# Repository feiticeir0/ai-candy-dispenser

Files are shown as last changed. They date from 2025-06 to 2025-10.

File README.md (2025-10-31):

# Candy Machine with Voice Recognition
<div style="text-align: center;">
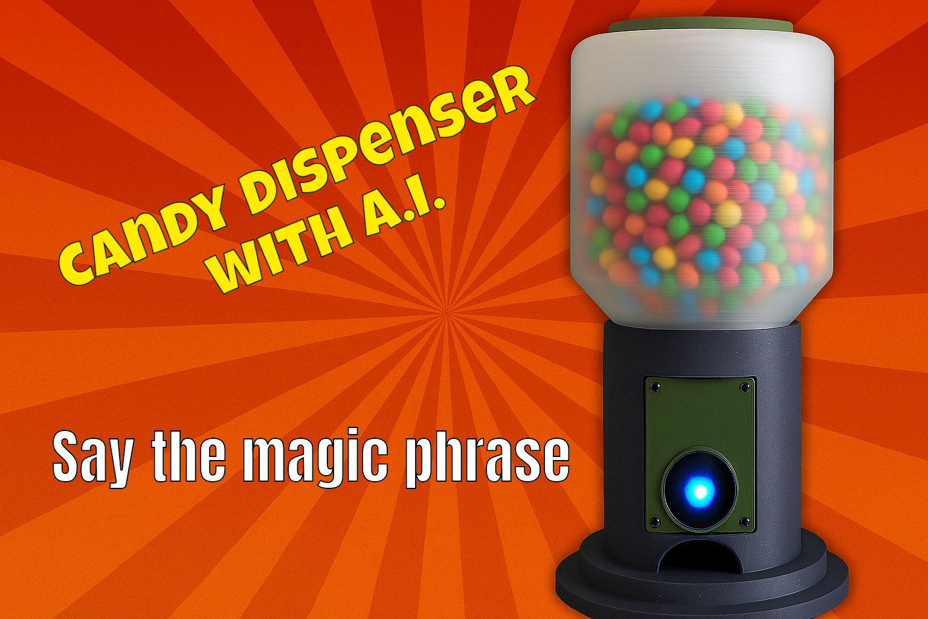
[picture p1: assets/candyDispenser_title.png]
    
</div>

This project is a tiny, AI-powered candy dispenser built with the Seeed Studio ESP32S3 Sense and the Xiao Round Display for XIAO.

Say the right magic words, and you’ll be rewarded with a cookie. 😄
If not, the screen politely tells you to try again.

---

## 📷 How It Works
1. When starting, the standy screen is shown

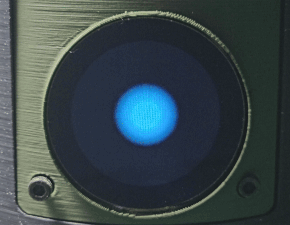
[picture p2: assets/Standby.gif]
Standby


2. The user presses the display.
3. The Xiao starts recording a phrase for **5 seconds**.

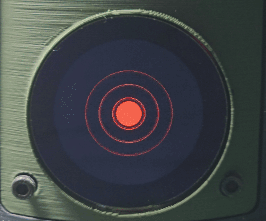
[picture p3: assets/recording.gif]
Recording


4. The phrase is sent to a **remote server**:
   - Automatically transcribes the audio using **Whisper** (OpenAI)
   - Classifies the phrase as **positive** or **negative** about chocolate or candy

5. While waitinng for a response from the server

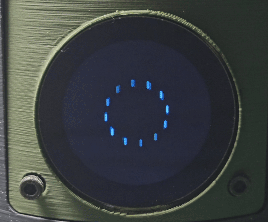
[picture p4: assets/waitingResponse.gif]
Waiting response


4. If the phrase is **positive**:

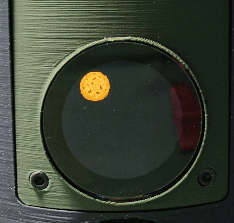
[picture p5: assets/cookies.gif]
Cookies

   - A candy is automatically **dispensed**

5. Otherwise, a image is shown asking the user to try again.

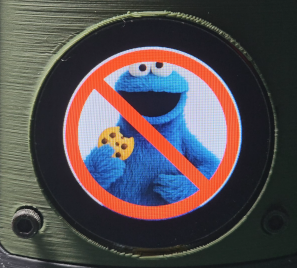
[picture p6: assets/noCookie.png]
No cookie for you


---

Project Structure

```
.
├── 3D/                       # Directory for the 3D models
├── Arduino/                  # Directory for the Arduino code
├── Jetson/                   # Directory for Jetson specific instructions
├── raspberry-pi-llm/         # Directory for running the server using a Raspberry PI
├── main.py                   # API code
├── Dockerfile                # Dockerfile for CPU
├── Dockerfile.gpu            # Dockerfile with CUDA support (GPU)
├── docker-compose.cpu.yml    # Compose file for CPU use
├── docker-compose.gpu.yml    # Compose file for GPU (NVIDIA)
```

---

## 📷 How to Use
## Server
### Deployment with Docker Compose
### ⚙️ Requirements

- Docker 20.10+
- `docker compose` (modern CLI)
- For GPU use:
  - NVIDIA drivers installed
  - `nvidia-container-toolkit`: [official guide](https://docs.nvidia.com/datacenter/cloud-native/container-toolkit/install-guide.html)

---

### 🖥️ Using with GPU (CUDA), building the image

Uses GPU to accelerate transcription and classification.

#### ✅ Requirements:

- NVIDIA GPU compatible with CUDA 11.8+
- Drivers installed (`nvidia-smi` should work)
- Docker with NVIDIA runtime
- Install the toolkit:
```bash
sudo apt-get install -y nvidia-container-toolkit
sudo systemctl restart docker
```

#### ▶️ Command:

```bash
docker compose -f docker-compose.gpu.yml up --build
```
After the command, it should start buiding the machine. 
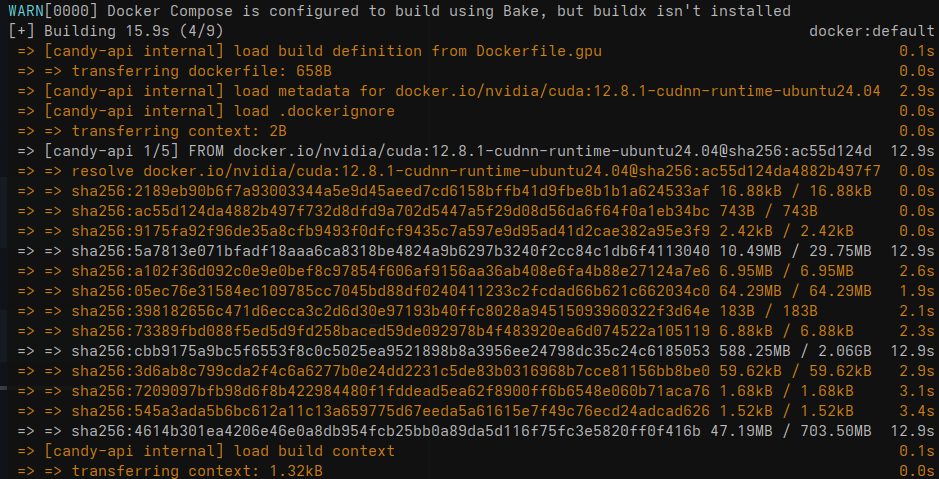
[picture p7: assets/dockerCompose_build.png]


---

### 🖥️ Using with CPU only, building the image

Simpler and portable; good for testing and light deployments.

#### ▶️ Command:

```bash
docker compose -f docker-compose.cpu.yml up --build
```

---

## ⚙️ Testing GPU (CUDA) Support

### ✅ 1. Check NVIDIA drivers
```bash
nvidia-smi
```

### ✅ 2. Install `nvidia-container-toolkit` (apt package)
```bash
sudo apt install nvidia-container-toolkit
sudo systemctl restart docker
```

### ✅ 3. Verify GPU access via Docker
```bash
docker run --rm --gpus all nvidia/cuda:11.8.0-base nvidia-smi
```

### ▶️ 4. Start with GPU (after building the image, above instructions)
```bash
docker compose -f docker-compose.gpu.yml up
```
After a bit, the container is ready and listening. 
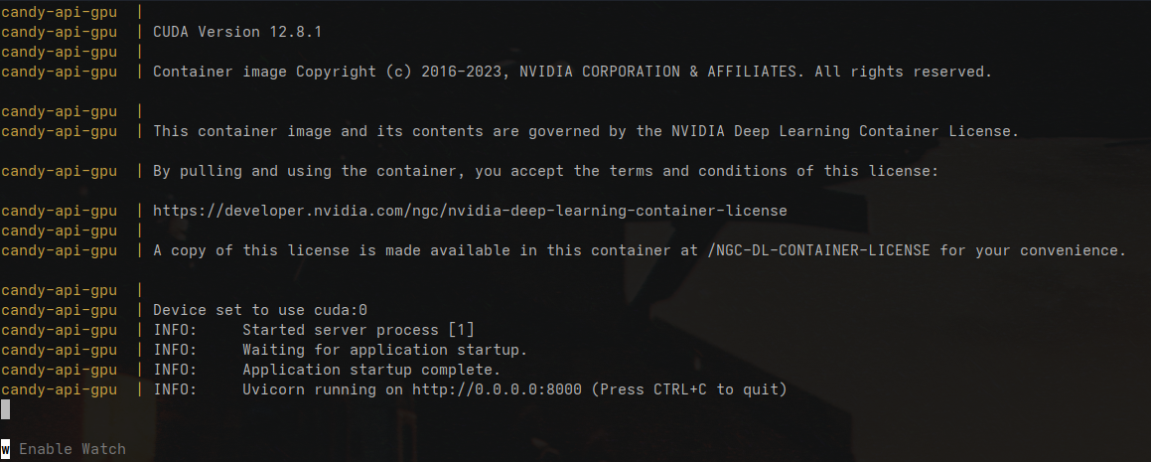
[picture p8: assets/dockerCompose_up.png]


### 5. Check if PyTorch uses CUDA
```bash
docker exec -it candy-api-gpu python3 -c "import torch; print(torch.cuda.is_available())"
```
---

## 🍬 Deployment with Jetson

If you're going to use a Nvidia Jetson (tested with Seeedstudio reComputer J4012 - Jetson Orin NX 16GB), go to [Jetson](./Jetson/README.md) folder for more information

---

## 📦 Models Used
These are the models used. You can change them in `main.py`.

- [`openai/whisper-small`](https://github.com/openai/whisper): for audio transcription
- [`facebook/bart-large-mnli`](https://huggingface.co/facebook/bart-large-mnli): for zero-shot classification

---

## Customization

- You can change the classification **labels** (`positive`, `negative`) in `main.py`
- You can switch Whisper models to `tiny`, `base`, or `large` depending on your hardware
- You can switch the language used by model for the transcription (`pt`, `en`, `es`, etc.)

### Everything is customizable

Instead of something about candy, it can be about anything. The Xiao records a 5 seconds phrase (customizable, but be aware of memory limitations - it's recorded on memory) and sends it to the server for transcription by whisper. There, you can **change** the classification labels and make it about anything. 

## 🔧 Auto-start on Boot (systemd)
For the docker image to start at boot, we need to create a Systemd file. 
Let's create the file
```bash
sudo vi /etc/systemd/system/candy-machine.service
```
Inside, place the following lines. **Here I'm using the docker compose GPU file**.

Don't forget to replace the location for your working directory, where the docker compose files are located. 

```
[Unit]
Description=Candy Machine API (Docker Compose)
Requires=docker.service
After=docker.service

[Service]
Type=oneshot
RemainAfterExit=yes
WorkingDirectory=/path/for/the/project
ExecStart=/usr/bin/docker compose -f docker-compose.cpu.yml up -d
ExecStop=/usr/bin/docker compose -f docker-compose.cpu.yml down
TimeoutStartSec=0

[Install]
WantedBy=multi-user.target
```
Reload Systemd and enable the new service.

```bash
sudo systemctl daemon-reexec
sudo systemctl daemon-reload
sudo systemctl enable candy-machine.service
```

Start it manually the first time.
```bash
sudo systemctl start candy-machine.service
```
Now, the Candy Machine will start automatically when the system starts. 

## ⚙️ Technical Notes & Troubleshooting
### 🧩 Display not showing graphics (white or black screen)

If the round display remains white or black while touch and Wi-Fi work, make sure you’re using the SeeedStudio TFT_eSPI library (not the official Bodmer version).

You can install it directly from Seeed’s GitHub:

https://github.com/Seeed-Studio/Seeed_Arduino_TFT_eSPI

### TFT_eSPI

Also verify that you’ve removed any conflicting versions of TFT_eSPI from your Arduino libraries folder before compiling.

#### ✅ Tested combination:
* Seeed_Arduino_TFT_eSPI (latest)
* PNGdec version 1.0.2 (older, keeps void callback compatibility)

### 🎧 Whisper and ffmpeg error on Jetson devices
When running the FastAPI server with systemd and a Python virtual environment, Whisper may fail with:
```bash
FileNotFoundError: [Errno 2] No such file or directory: 'ffmpeg'
```

This happens because systemd launches services with a minimal PATH that doesn’t include /usr/bin.
To fix this, the following lines are at the very beginning of main.py:
```python
# Whisper & ffmpeg fix for Jetson + systemd
import os
os.environ["PATH"] += os.pathsep + "/usr/bin:/usr/local/bin"
```
This ensures ffmpeg is always found, even when the server is started automatically at boot.
- Tested on Jetson Orin NX (JetPack 6.0)
- Environment: Python 3.10 virtualenv + systemd service

## Client (the candy dispenser)
### 3D Files
Go to the [3D](./3D/readme.md) folder for more information.

### Schematics
Go to the [Schematics](./Schematics/readme.md) folder for more information on how to wire the project. 

### Arduino Code
Go to the [Arduino](./Arduino/readme.md) folder for more information.

## 🔧 TODO
- [ ] :bulb: Add a sensor to detect motor rotation (make sure a candy exits)
- [ ] :bulb: Migrate the FastAPI server to work with a Raspbery PI AI Hat+ 
- [ ] :bulb: Check for network connection in the Xiao

# Result
Here's a video of the project running (https://www.youtube.com/watch?v=d_zhMSL0ufM)

## License
This project is free software: you can redistribute it and/or modify  
it under the terms of the [GNU General Public License](https://www.gnu.org/licenses/gpl-3.0.en.html)  
as published by the Free Software Foundation, either version 3 of the License,  
or (at your option) any later version.

This project is distributed in the hope that it will be useful,  
but WITHOUT ANY WARRANTY; without even the implied warranty of  
MERCHANTABILITY or FITNESS FOR A PARTICULAR PURPOSE. See the GNU General Public License for more details.

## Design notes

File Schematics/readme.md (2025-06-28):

## Schematics for the Candy Machine

Here are the schematics for the Candy Machine electronics component. 

You'll need:
- Seeedstudio ESP32S3 Sense (you must remove the camera)

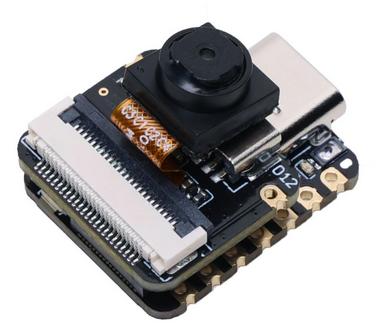
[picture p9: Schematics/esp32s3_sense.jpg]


- Seeedstudio Round display for Xiao

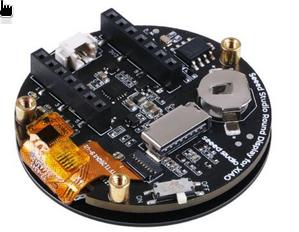
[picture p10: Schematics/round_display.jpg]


- MX1508 motor shied

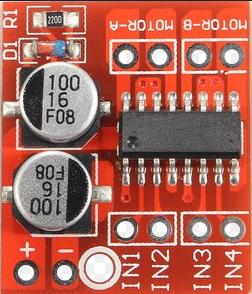
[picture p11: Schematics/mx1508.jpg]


- DC 6V Mini Gear Motor right angle

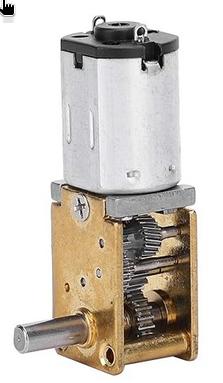
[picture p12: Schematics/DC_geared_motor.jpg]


## Schematics
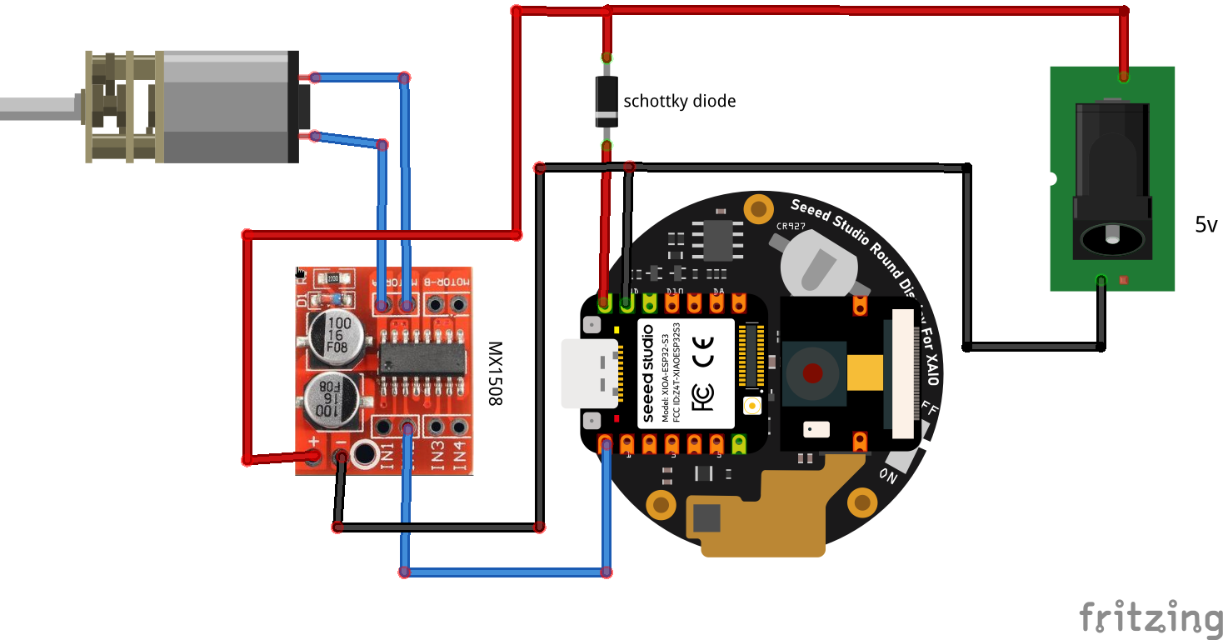
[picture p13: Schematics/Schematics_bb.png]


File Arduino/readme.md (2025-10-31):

## :electric_plug: Multitasking with FreeRTOS on the Xiao ESP323 Sense

We use the power of the ESP32-S3's dual-core architecture and the built-in FreeRTOS real-time operating system to run multiple tasks simultaneously.

We use parallel tasks (xTaskCreatePinnedToCore) to separate the application's logic into well-defined states.

### :dart: Main tasks:
```
    standbyTask: breathing animation while waiting for touch interaction.
    gravacaoTask: audio recording using the PDM microphone.
    sendTask: HTTP POST to the API and spinning loader animation.
    recordingVisualTask: animated ripple effect during recording.
    cookieTask: cookie animation + motor control to dispense the treat.
    noCookieTask: visual feedback when no cookie is dispensed.
```

### 🧩 Task coordination:
```
    Clear application states are defined to represent each phase of operation.
    A binary semaphore (semState) is used to signal and switch between tasks safely.
    Some tasks use flags (e.g., recordingVisualShouldStop) to exit gracefully and keep transitions visually coherent.
```

### ⚙️ Performance on XIAO ESP32S3 Sense

Despite its tiny form factor, the XIAO ESP32S3 Sense handles everything — from Wi-Fi connectivity and I2S audio capture to real-time sprite rendering on Round display for Xiao — all thanks to the multitasking provided by FreeRTOS.

### Uploading Code to the Seeed Studio Xiao ESP32S3 Sense

To run the Candy Machine on the Xiao ESP32S3 Sense, with microphone and the LCD (Xiao round display for XIAO), we need to configure the Arduino IDE development environment properly.

### ✅ Requirements

- Arduino IDE installed
- ESP32-S3 board added via **Boards Manager** (Espressif)
- Official `ESP32` library (v2.0.7 or higher recommended)

### Libraries
- `TFT_eSPI` - It must be from SeeedStudio - https://github.com/Seeed-Projects/SeeedStudio_TFT_eSPI
- `ArduinoJSON`
- `PNGdec` (version 1.0.2 or lower)
- `Wire`

#### Custom libraries (included in the repository)
- `CHSC6X_Touch.h` **( Xiao Round Display Touch screen)**
- `cookie.h`       **(cookie image)**
- `no_cookies.h`   **(no cookie image)**
---

Under  [files](./files) directory you'll find all the needed files for the client. 

### ⚙️ Required Settings in Arduino IDE

Set these under **Tools**:

- **PSRAM**: ✔️ Enabled ✅ required for audio/transcription
- **Flash Size:**: "8MB (64Mb)"

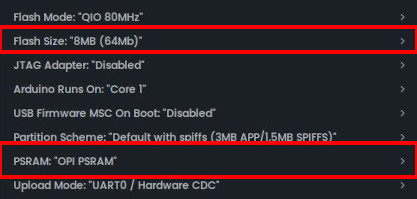
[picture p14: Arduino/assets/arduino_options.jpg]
Options


## ⚠️ Warning
You can't change much regarding the Xiao Pins. Some are used by the Sense, others by the Round Display, I2C, etc.
There aren't many available. 

You can read more about it on Seeedstudio Wiki
[https://wiki.seeedstudio.com/xiao_esp32s3_pin_multiplexing/](https://wiki.seeedstudio.com/xiao_esp32s3_pin_multiplexing/)
[https://wiki.seeedstudio.com/xiao_esp32s3_getting_started/](https://wiki.seeedstudio.com/xiao_esp32s3_getting_started/)

## :hammer: Options to change
You need to change some variables in the code. 

### WiFi Network

```c
// Change here your wifi password and network
const char* ssid = "<your_wifi_ssid>";
const char* password = "<your_wifi_network_passsword>";

// change here the IP of the server - change change the IP address, nothing else
const char* apiUrl = "http://<your_server_IP>:8000/analyze-audio"; 
```

### :record_button: Recording
By default, we record a 5 seconds phrase. If you want to record more or less, you need to change the following variable
```c
// Time in seconds to record
#define RECORD_TIME 5
```
Change the 5 for the number of seconds you want to record. 

### Motor rotation
By default, and after some testing for this motor, 1s is enough for a full rotation. If your motor takes longer or less to a full rotation (to make sure a candy exits), you need to adjust the following variable, that resides in the **cookieTask** function. The value is in miliseconds. 
```c
const unsigned long duration = 1000; // how long the motor turns
```

## :framed_picture: Images
The displayed images are C flash arrays.

The instructions are inside the TFT_eSPI examples, Flash_PNG sketch. 
```
// Image files can be converted to arrays using the tool here:
// https://notisrac.github.io/FileToCArray/
// To use this tool:
//   1. Drag and drop file on "Browse..." button
//   2. Tick box "Treat as binary"
//   3. Click "Convert"
//   4. Click "Save as file" and move the header file to sketch folder
//   5. Open the sketch in IDE
//   6. Include the header file containing the array 
```
We have *cookie.h* and *no_cookies.h* files, that are C Flash Arrays . 

## Code explanation
There are several functions along the code that require some in depth explain. 

### Tasks

We're defining here the several tasks that we're going to go through as FreeRTOS tasks. This is necessary for the multitasking that we're going to be using - showing animations while performing several other functions on the background. 

```c
SemaphoreHandle_t semState = NULL;
TaskHandle_t taskHandles[6]; // standby, gravacao, send, cookies, noCookies, recordingVisual
```

### void sendTask(void* param)
This function will send the recording to the server using HTTP Post method. 
```c
WiFiClient client;
HTTPClient http;
http.begin(client, apiUrl);
http.addHeader("Content-Type", "audio/wav");
int code = http.POST(wav_buffer, wav_size);
```
It then displays an animation while waiting
```c
 // animation
    for (int f = 0; f < 150; f++) {
      sprite.fillSprite(TFT_BLACK);
      for (int i = 0; i < numBars; i++) {
        float angle = (frame * 4 + i * angleStep) * DEG_TO_RAD;
        float x = 120 + cos(angle) * radius;
        float y = 120 + sin(angle) * radius;
        float glowFactor = (sin((frame * 0.15) + i) + 1.0) / 2.0;
        float coreAlpha = 0.4 + 0.6 * glowFactor;
        float outerAlpha = 0.2 * glowFactor;
        uint16_t coreColor = dimColor(baseColor, coreAlpha);
        uint16_t glowColor = dimColor(baseColor, outerAlpha);
        sprite.fillRoundRect(x - barWidth / 2, y - barLength / 2, barWidth, barLength, 2, glowColor);
        sprite.fillRoundRect(x - barWidth / 2, y - barLength / 2, barWidth, barLength, 2, coreColor);
      }
      sprite.pushSprite(0, 0);
      frame++;
      vTaskDelay(pdMS_TO_TICKS(20));
    }
```
Because we're using FreeRTOS tasks, we can't use **delay**, but instead we use **vTaskDelay(pdMS_TO_TICKS)**, where it converts the ticks to milliseconds. 

When the resulting code arrives, we check it. If it's greater than 0, we proceded to check the returning JSON payload. 

If it's *positivo* (positive), we change the state to **COOKIE** (we're going to dispense a cookie). If not, the state is changed to **NO_COOKIE** and no cookie will be given .

```c
if (code > 0) {
      String payload = http.getString();
      StaticJsonDocument<256> doc;
      if (!deserializeJson(doc, payload)) {
        bool positivo = doc["positivo"];
        changeState(positivo ? COOKIE : NO_COOKIE);
      } else changeState(NO_COOKIE);
    } else changeState(NO_COOKIE);

    http.end();
  }
```

### void gravacaoTask(void* param)
This is the function that will record the 5s phrase. We're in loop (athough not necessary) because FreeRTOS requires it for the tasks. But it doesn't interferes because the task is suspended after the recording. 

If the current state is not recording, we stop it right here. 
```c
if (currentState != RECORDING) vTaskSuspend(NULL);
```

We start by declaring the I2SClass varible to record the audio. We set the PINs (by Xiao ESP32S3 documentation), set the environment of the recoring and start recording. 

```c
 I2SClass i2s;
    i2s.setPinsPdmRx(42, 41);
    i2s.begin(I2S_MODE_PDM_RX, 16000, I2S_DATA_BIT_WIDTH_16BIT, I2S_SLOT_MODE_MONO);
    uint8_t* buf = i2s.recordWAV(RECORD_TIME, &wav_size);
```
After the recording, we copy the buffer to another buffer **
```c
memcpy(wav_buffer, buf, wav_size);
```
We then free the buffer. 
```c
free(buf);
```

Unlike all the other tasks, we here set a global variable as true for the recording animation to stop. 
```c
recordingVisualShouldStop = true;
```
This task was suspending another task (**recordingVisualTask**) without having the assurance that was ocurring on the same core. 

⚠️  **Classical error on FreeRTOS**

"One task must not suspend another task that's potencially running on another core". 

And that was the case. 
By replacing the **vTaskSuspend** with a signal for it to self-suspend, all the problems went away. 

Here's the code on the **recordingVisualTask** function that checks for the signal:
```c
 if (currentState != RECORDING || recordingVisualShouldStop) {
      recordingVisualShouldStop = false;  // clears the flag
      vTaskSuspend(NULL);
    }
```

I must thank **ChatGPT** for this. It was able to spot the problem and provide a solution for it. 

After copying the buffer, we change the state to **SENDING**

### void changeState(AppState newState)
This is the function responsable for changing the states and using the FreeRTOS semaphores for synchronization between tasks.
```c
  currentState = newState;

  xSemaphoreGive(semState);
  switch (newState) {
    case STANDBY:    vTaskResume(taskHandles[0]); break;
    case RECORDING:
      vTaskResume(taskHandles[1]);
      vTaskResume(taskHandles[5]);
      break;
    case SENDING:    vTaskResume(taskHandles[2]); break;
    case COOKIE:     vTaskResume(taskHandles[3]); break;
    case NO_COOKIE:  vTaskResume(taskHandles[4]); break;
  }
}
```

The taks are a **enum** type
```c
enum AppState {
  STANDBY,
  RECORDING,
  SENDING,
  COOKIE,
  NO_COOKIE
} currentState = STANDBY;
```

In the begining of the file, we define a TaskHandle_t array big enough of the several tasks. 

```c
SemaphoreHandle_t semState = NULL;
TaskHandle_t taskHandles[6]; // standby, gravacao, send, cookies, noCookies, recordingVisual
```
We have 6 tasks, and, instead of defining 6 TaskHandle_t variables, just the one. 

On the **setup()** function, we define the semaphores:
```c
  semState = xSemaphoreCreateBinary();
  xTaskCreatePinnedToCore(standbyTask, "standby", 4096, NULL, 1, &taskHandles[0], 0);
  xTaskCreatePinnedToCore(gravacaoTask, "gravacao", 4096, NULL, 1, &taskHandles[1], 0);
  xTaskCreatePinnedToCore(sendTask, "send", 4096, NULL, 1, &taskHandles[2], 0);
  xTaskCreatePinnedToCore(cookieTask, "cookie", 2048, NULL, 1, &taskHandles[3], 0);
  xTaskCreatePinnedToCore(noCookieTask, "nocookie", 2048, NULL, 1, &taskHandles[4], 0);
  xTaskCreatePinnedToCore(recordingVisualTask, "recordVis", 2048, NULL, 1, &taskHandles[5], 0);
```

You can check more about them here:

[https://www.freertos.org/Documentation/02-Kernel/02-Kernel-features/01-Tasks-and-co-routines/00-Tasks-and-co-routines](https://www.freertos.org/Documentation/02-Kernel/02-Kernel-features/01-Tasks-and-co-routines/00-Tasks-and-co-routines)

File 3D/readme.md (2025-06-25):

## 3D files for printing

#### The Candy dispenser is a simple 3D model that can be printed using a 3D printer.

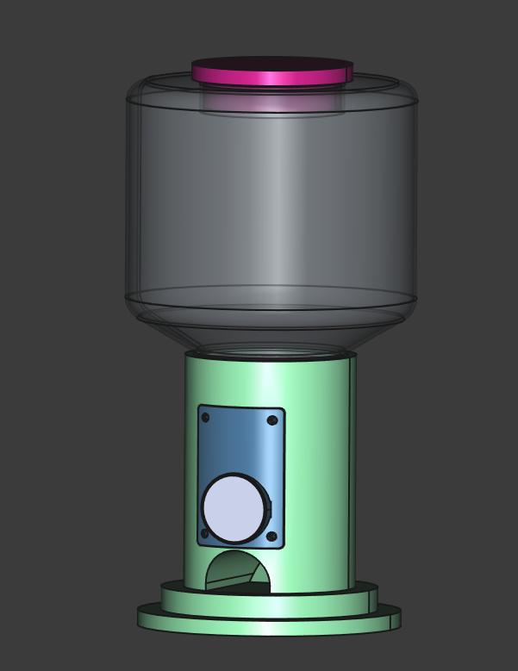
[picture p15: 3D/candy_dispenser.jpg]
Candy Dispenser


### Candy structure
The candy assembles with 6 parts:
1. The base
2. The electronics component
3. The rotating cylinder
4. The N20 Geared DC motor support
5. The candy jar
6. the candy jar cap

#### The Base
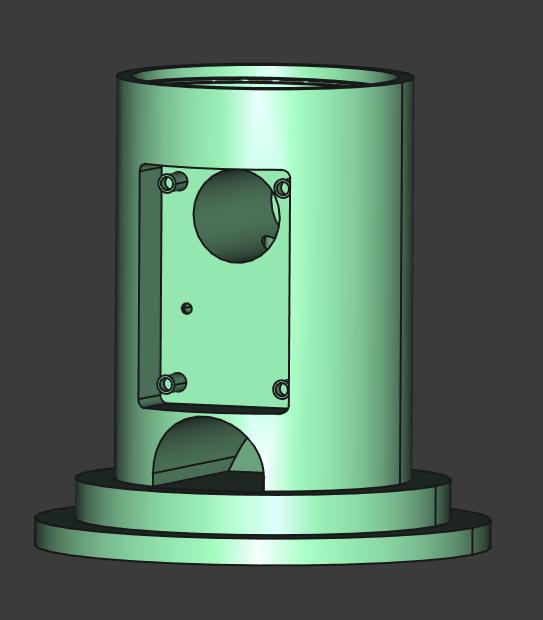
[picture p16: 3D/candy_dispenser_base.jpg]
Candy Base

#### The electronics component
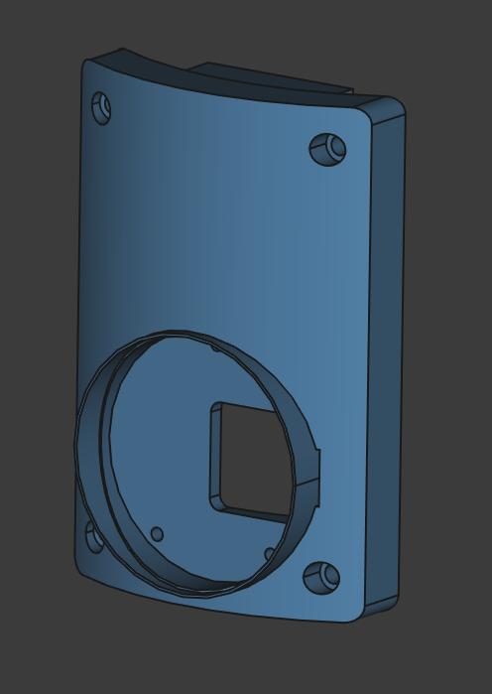
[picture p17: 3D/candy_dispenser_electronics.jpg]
Candy Electronics

#### The rotating cylinder
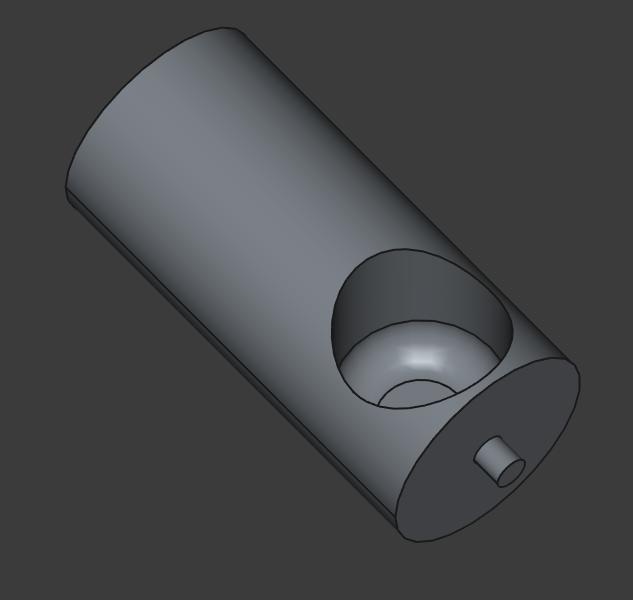
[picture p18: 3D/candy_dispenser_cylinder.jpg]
Candy Cylinder

#### The N20 Geared DC Motor support
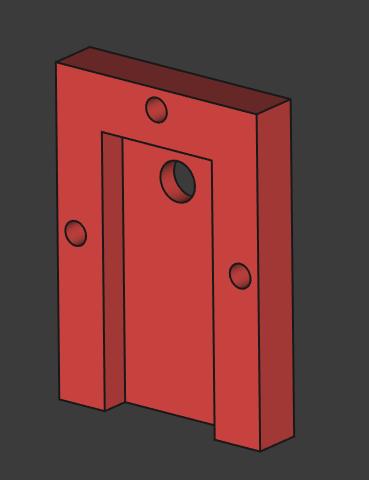
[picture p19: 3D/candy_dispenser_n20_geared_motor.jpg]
Candy N20 Geared DC Motor support

#### The Candy Jar
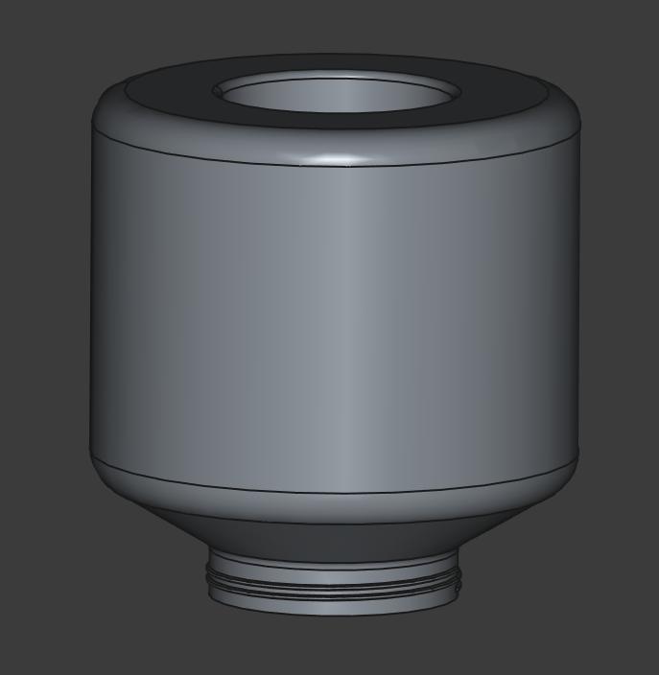
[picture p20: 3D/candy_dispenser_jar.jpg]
Candy Jar

#### The Candy Jar Cap
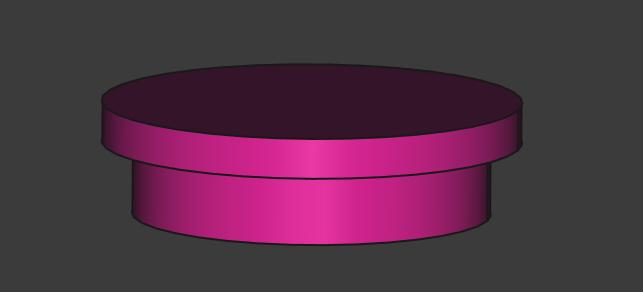
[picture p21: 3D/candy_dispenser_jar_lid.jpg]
Candy Jar Lid


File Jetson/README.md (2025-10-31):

## 🍬 Jetson Deployment Guide
### Overview

This document explains how to deploy the Candy Dispenser API on a Jetson Orin NX (or any Jetson device running JetPack 6+).
It covers creating a Python virtual environment, installing dependencies, configuring systemd for automatic startup, and solving common issues with ffmpeg and Whisper.

## 🧩 Requirements

- Ubuntu 20.04 / 22.04 (JetPack 6.x)
- Python 3.10+
- ffmpeg installed system-wide
```bash
sudo apt update
sudo apt install ffmpeg
```
- Internet connection for initial dependency installation

## 🐍 1. Create the virtual environment
```bash
cd ~
python3 -m venv candy-api
source candy-api/bin/activate
```
Upgrade pip and install dependencies:

```bash
pip install --upgrade pip
pip install fastapi uvicorn[standard] pydub
```
### Jetson Specific Pytorch packages
To install a supported Pytorch version, head up to Nvidia forums and follow the instructions according to your JetPack version.

https://forums.developer.nvidia.com/t/pytorch-for-jetson/72048

After installing PyTorch, install Whisper
```bash
 pip install git+https://github.com/openai/whisper.git \
 ```

## ⚙️ 2. Verify ffmpeg
Check that ffmpeg is accessible:
```bash
which ffmpeg
# Expected output: /usr/bin/ffmpeg
```
If this returns nothing, install it again or adjust your PATH.

## 🧠 3. Fix ffmpeg visibility for systemd
When running as a system service, systemd uses a limited PATH.
To make sure Whisper can find ffmpeg, add this snippet at the very top of your main.py:
```bash
# Fix for ffmpeg visibility under systemd
import os
os.environ["PATH"] += os.pathsep + "/usr/bin:/usr/local/bin"
```
## 🔧 4. Create the systemd service
Create the new files, changing <your_user> for your user:
```bash
sudo nano /etc/systemd/system/candy-api.service
```
Paste the following configuration:
```bash
[Unit]
Description=Candy Dispenser FastAPI Service
After=network.target

[Service]
User=<your_user>
WorkingDirectory=/home/<your_user>/candy-api
ExecStart=/home/<your_user>/candy-api/bin/uvicorn main:app --host=0.0.0.0 --port=8000
Environment=PATH=/usr/local/sbin:/usr/local/bin:/usr/sbin:/usr/bin:/sbin:/bin:/home/<your_user>/candy-api/bin
Restart=always
RestartSec=5
StandardOutput=append:/var/log/candy-api.log
StandardError=append:/var/log/candy-api.log

[Install]
WantedBy=multi-user.target
```
Save and enable the service:
```bash
sudo systemctl daemon-reexec
sudo systemctl daemon-reload
sudo systemctl enable candy-api
sudo systemctl start candy-api
```

## 📋 5. Check status and logs
To confirm that the service is running:
```bash
systemctl status candy-api
```
To view logs in real time:
```bash
journalctl -u candy-api -f
```
Logs are also written to /var/log/candy-api.log.

## 🧼 6. Maintenance commands
```bash
sudo systemctl restart candy-api
```
Stop the service:
```bash
sudo systemctl stop candy-api
```
Update dependencies:
```bash
source ~/Documents/candy-api/venv/bin/activate
pip install -U <package>
sudo systemctl restart candy-api
```

## 🧠 Notes
- If you later migrate to a Docker deployment, remove the os.environ["PATH"] fix and install ffmpeg inside the image (apt-get install -y ffmpeg).
- Always test Whisper locally before enabling the service:
```bash
source venv/bin/activate
python -m whisper test.wav
```
## ✅ Result
After following this guide, the API will:
- start automatically at boot,
- have full access to ffmpeg,
- run inside an isolated virtual environment,
- and log output to /var/log/candy-api.log.

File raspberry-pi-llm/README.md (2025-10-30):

# Using Raspberry PI has the server
We can also use a Rasbpberry PI 5 has a server for the Candy Machine. 
We need a PI5 because we need to use a LLM for the transcription and analysis.

We're going to use Ollama for the language model and Whisper.cpp for the audio transcription.

## Project structure
Here's the project structure to use the Raspberry PI has the server for the Candy Dispenser
```

raspberry-pi-llm/
├── docker-compose.yml
├── server/
│   ├── Dockerfile
│   ├── server.py
│   ├── .env
│   └── whisper.cpp/         # included in the container
```
### Files
#### 📄 .env
```bash
OLLAMA_URL=http://localhost:11434
WHISPER_MODEL=./whisper.cpp/models/ggml-base.en.bin
```
#### 📄 docker-compose.yml
```
services:
  ollama:
    image: ollama/ollama:latest
    container_name: ollama
    restart: unless-stopped
    ports:
      - "11434:11434"
    volumes:
      - ollama_data:/root/.ollama

volumes:
  ollama_data:
```

#### 📄 candy-server.py
```python
from fastapi import FastAPI, UploadFile
from fastapi.responses import JSONResponse
import uvicorn
import subprocess
import tempfile
import os
import requests
from dotenv import load_dotenv

load_dotenv()

OLLAMA_URL = os.getenv("OLLAMA_URL", "http://localhost:11434")
WHISPER_MODEL = os.getenv("WHISPER_MODEL", "./whisper.cpp/models/ggml-base.en.bin")

app = FastAPI()

@app.post("/audio")
async def receive_audio(file: UploadFile):
    # Guarda o áudio recebido temporariamente
    with tempfile.NamedTemporaryFile(delete=False, suffix=".wav") as tmp:
        tmp.write(await file.read())
        wav_path = tmp.name

    # Executa whisper.cpp
    result = subprocess.run([
        "./whisper.cpp/main",
        "-m", WHISPER_MODEL,
        "-f", wav_path,
        "-otxt"
    ])

    txt_path = wav_path.replace(".wav", ".txt")
    if not os.path.exists(txt_path):
        return JSONResponse(status_code=500, content={"error": "Erro na transcrição"})

    with open(txt_path, 'r') as f:
        transcription = f.read().strip()

    os.remove(wav_path)
    os.remove(txt_path)

    # Prepara prompt
    prompt = f'A criança disse: "{transcription}". Esta frase está relacionada com doces? Responde apenas com SIM ou NÃO.'

    try:
        response = requests.post(f"{OLLAMA_URL}/api/generate", json={
            "model": "phi3:mini",
            "prompt": prompt,
            "stream": False
        })

        resposta = response.json()["response"].strip().upper()
        is_positive = "SIM" in resposta

    except Exception as e:
        return JSONResponse(status_code=500, content={"error": f"Erro no modelo: {str(e)}"})

    return JSONResponse(content={
        "positivo": is_positive,
        "text": transcription
    })

if __name__ == "__main__":
    uvicorn.run("server:app", host="0.0.0.0", port=5000)
```

## Docker
Like with the reComputer, let's use docker with Ollama for a better handling and cleaner approach. 

### Install docker
You can find the instructions on the following link: [https://docs.docker.com/engine/install/debian/](https://docs.docker.com/engine/install/debian/)

Docker documentation recommends using the Debian instructions for the 64bit version of Raspbian. 

If you're using the 32bits version, you can follow these instructions: [https://docs.docker.com/engine/install/raspberry-pi-os/](https://docs.docker.com/engine/install/raspberry-pi-os/)

Add pi user (or the user you're using) to the docker group so we use docker as a normal user
```bash
sudo gpasswd -a pi docker
```

Logout and login again
## Clone the repository
How to clone this

## Server build
Our fina goal will be:
| Service | Function | Execution |
| --- | --- | --- |
| `ollama` | LLM via API REST | Isolated Container
| `Candy-server` | FastAPI + Whisper.cpp + application logic | Container that builds  whisper.cpp |

This will be two containers. One running ollama and the other one running our server, that will use Ollama API. 

### Pull and run Ollama docker
```bash
docker compose up -d
```
The Ollama image should start being pulled
pulling

After a while, you should have the image created. Let's see if it's running:
```bash
curl http://localhost:11434
```
And the result should be:
```
Ollama is running
```
#### Pull the desired model
We can use any model we want, as long it does what we need. Here's an example of a possible prompt:
```
The children said: "I want a cookie". 
Is this phrase candy related?
It answers with Positive or Negative.
```
This are possible models that we can use:
- llama3:instruct
- mistral:instruct
- phi3:mini

Let's use phi3:mini.

Pull the model (Ollama must be running). We can use the API that Ollama exposes, on port 11434, or the CLI.
```bash
curl http://localhost:11434/api/pull -d '{"name": "phi3:mini"}'
```
After a while, a success message should appear. 

## Docker image for the server
Let's now create a docker image, using docker container, for our server to run. This way, we don't have to create a Virtual Environment and it will keep all clean. 

### Whisper.cpp
We're going to use Whisper.cpp for the transcription. Our docker image wil take care of that. 

#### The model. 
You can read more about Whisper.cpp models here:

[https://github.com/ggml-org/whisper.cpp/blob/master/models/README.md](https://github.com/ggml-org/whisper.cpp/blob/master/models/README.md)

By default, in the .env file, the model used is a multilingue model, sso it can understand Portuguese. 

If you need a different model, let's say for the English language, change it in the [Dockerfile](./server/Dockerfile) inside the server directory. 

Locate the following section inside the file:
```
# Clones and compiles whisper.cpp inside the container
RUN git clone https://github.com/ggerganov/whisper.cpp && \
    cd whisper.cpp && make -j && \
    ./models/download-ggml-model.sh small
```
In this line `./models/download-ggml-model.sh small`, change `small`for the desired model, like `base.en`

Read the documentation for mode options.

Now, we need to change the **.env** file to use this new model.
```bash
vi .env
```
change

`WHISPER_MODEL=./whisper.cpp/models/ggml-small.bin`

to:

`WHISPER_MODEL=./whisper.cpp/models/ggml-base.en.bin`

### Build the image
To build the image, let's use docker compose.
```bash
cd raspberry-pi-llm
docker compose up --build -d
```
It should start building the image, that will include compilling Whisper.cpp

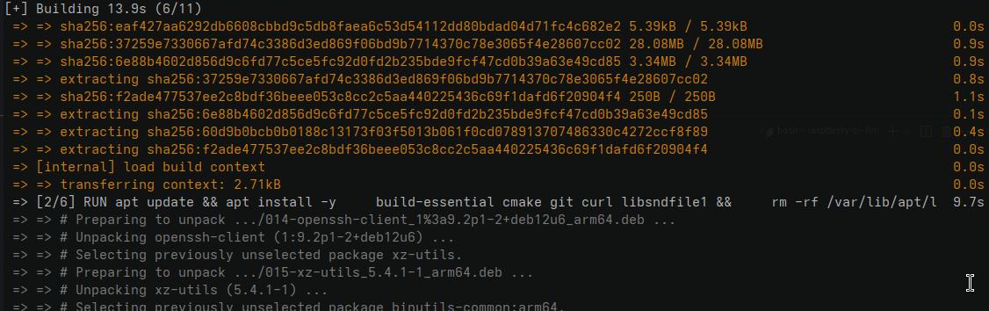
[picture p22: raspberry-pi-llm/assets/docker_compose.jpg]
Buiding the image


After a while, the image is build and the container is run .

To stop the container, just run, inside the raspberry-pi-llm (where the docker-compose.yml is):
```
docker compose stop

[+] Stopping 1/1
 ✔ Container candy-server  Stopped
 ```
To start it again
```
docker compose start
[+] Running 1/1
 ✔ Container candy-server  Started 
```

To see all the containers running:
```
docker container ls
```
Containers

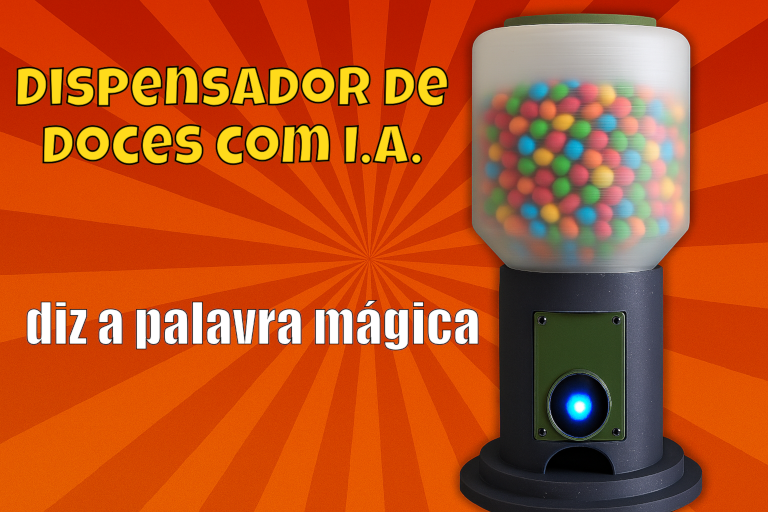
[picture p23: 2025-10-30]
assets/candyDispenser_titulo.png

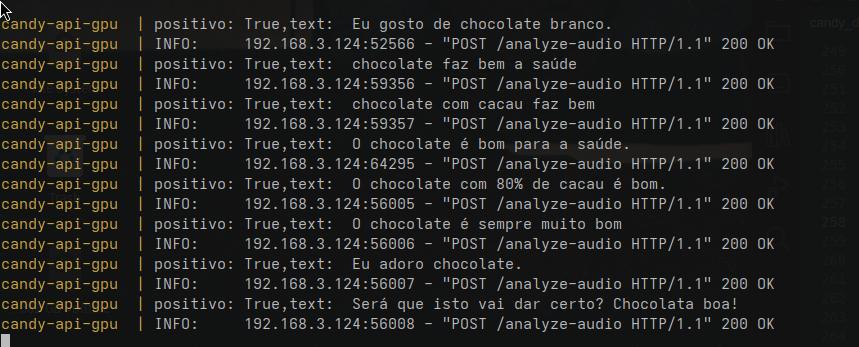
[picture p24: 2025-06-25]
assets/server_transcription.jpg

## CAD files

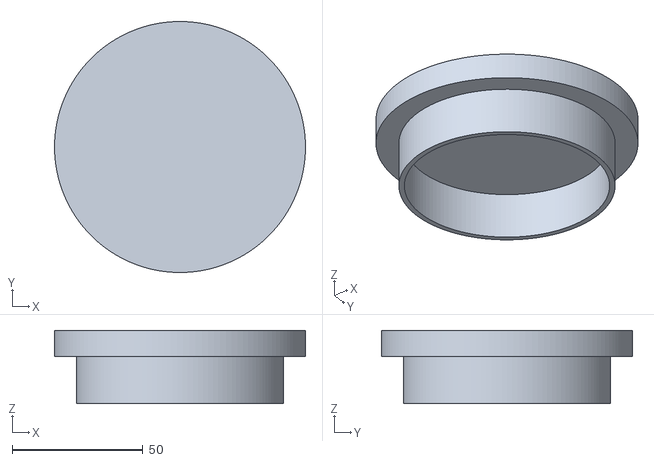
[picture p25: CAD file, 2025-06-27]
3D/STLs/CandyDispenser_jar_lid.stl
96.0 x 96.0 x 28.0

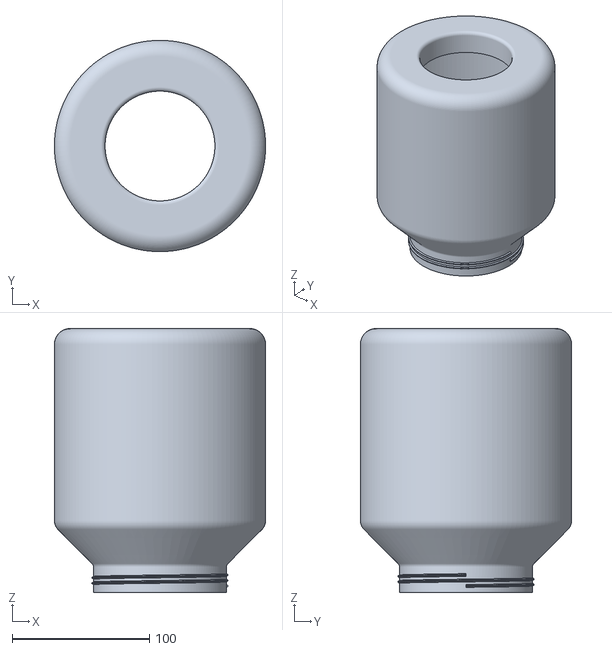
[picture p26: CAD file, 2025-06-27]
3D/STLs/CandyDispenser_jar.stl
154.0 x 154.0 x 192.5

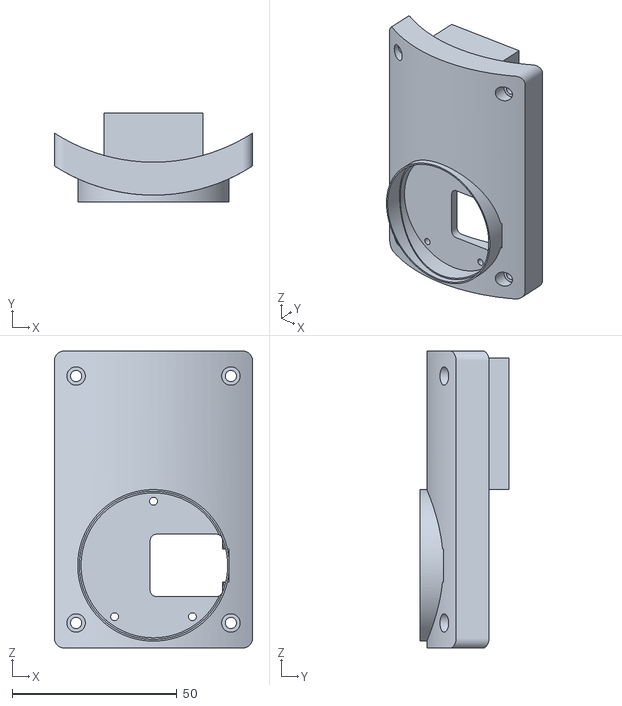
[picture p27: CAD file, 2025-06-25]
3D/STLs/CandyDispenser_electronics.stl
60.2 x 26.9 x 90.2

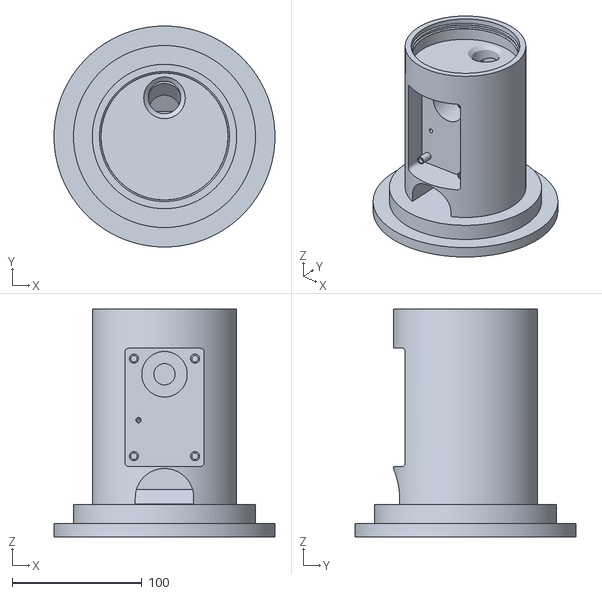
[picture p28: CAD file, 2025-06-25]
3D/STLs/CandyDispenser_base.stl
170.0 x 170.0 x 175.0

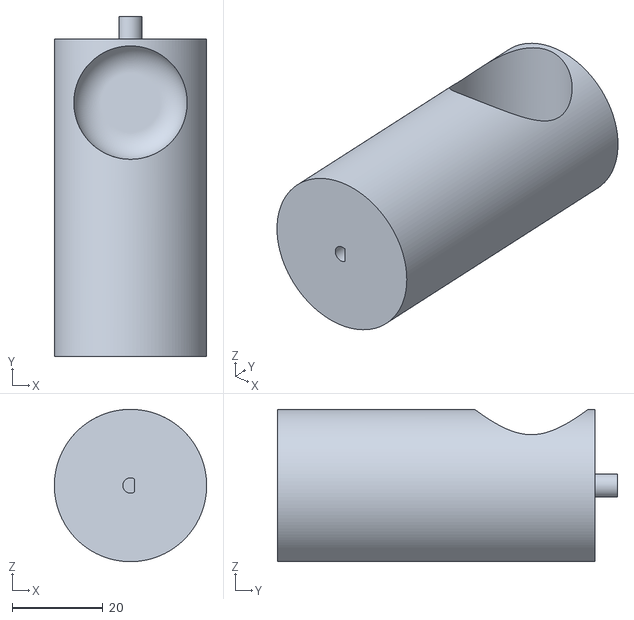
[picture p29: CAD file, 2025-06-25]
3D/STLs/CandyDispenser_cylinder.stl
33.6 x 75.0 x 33.6

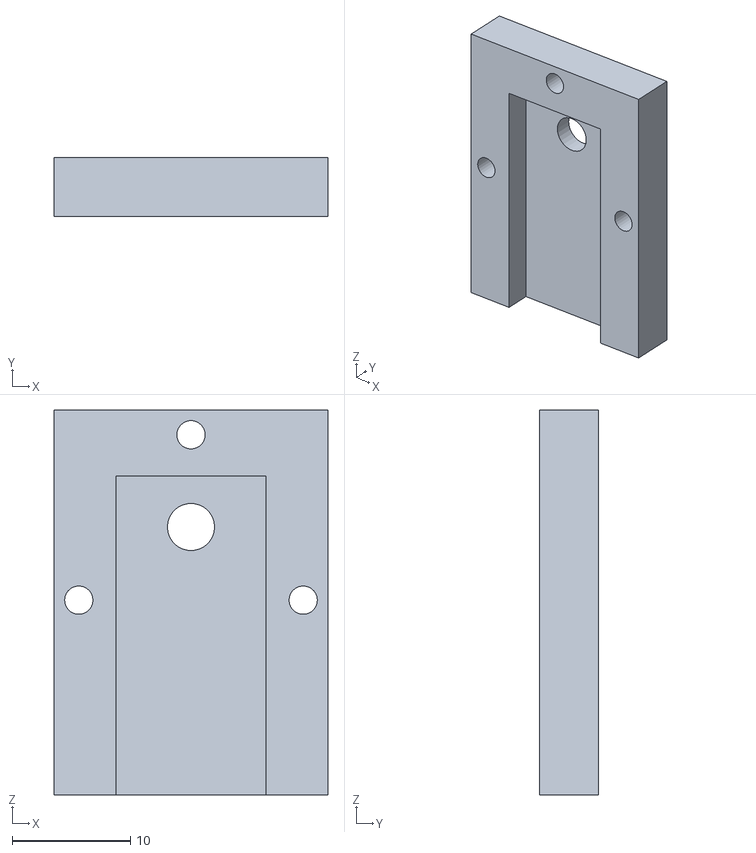
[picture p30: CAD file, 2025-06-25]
3D/STLs/CandyDispenser_N20_Motor_Geared.stl
23.2 x 5.00 x 32.6

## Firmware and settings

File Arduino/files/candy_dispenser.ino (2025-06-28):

/*
 * Nome do ficheiro: candy_dispenser.ino
 * Autor: Bruno Ricardo Santos - feiticeir0@whatgeek.com.pt (c) 2025
 * Licença: GNU General Public License v3.0 (GPLv3)
 *
 * Este programa é software livre: pode redistribuí-lo e/ou modificá-lo
 * sob os termos da Licença Pública Geral GNU conforme publicada pela Free Software Foundation,
 * quer a versão 3 da Licença, ou (a teu critério) qualquer versão posterior.
 *
 * Este programa é distribuído na expectativa de que seja útil,
 * mas SEM QUALQUER GARANTIA; sem mesmo a garantia implícita
 * de COMERCIALIZAÇÃO ou ADEQUAÇÃO A UM DETERMINADO FIM.
 * Veja a Licença Pública Geral GNU para mais detalhes.
 *
 * Deverás ter recebido uma cópia da Licença Pública Geral GNU
 * juntamente com este programa. Se não, veja <https://www.gnu.org/licenses/>.
 */

#include <WiFi.h>
#include <HTTPClient.h>
#include <TFT_eSPI.h>
#include <math.h>
#include <ArduinoJson.h>
#include "CHSC6X_Touch.h"
#include "ESP_I2S.h"
#include <PNGdec.h>
#include "cookie.h"
#include "no_cookies.h"

// Motor PIN
#define DISPENSER_PIN_2 D0

// Time in seconds to record
#define RECORD_TIME 5

#define MAX_WAV_SIZE (16000 * 2 * RECORD_TIME) // 5s a 16kHz mono 16-bit

#define MAX_IMAGE_WIDTH 240
#define DEG_TO_RAD 0.0174532925


// Change here your wifi password and network
const char* ssid = "<wifi_network_name>";
const char* password = "<wifi_password>";

// change here the IP of the server - change change the IP address, nothing else
const char* apiUrl = "http://<server_ip_address>:8000/analyze-audio";

TFT_eSPI tft;
TFT_eSprite sprite = TFT_eSprite(&tft);
CHSC6X_Touch touch;
PNG png;

uint8_t wav_buffer[MAX_WAV_SIZE];
size_t wav_size;

SemaphoreHandle_t semState = NULL;
TaskHandle_t taskHandles[6]; // standby, gravacao, send, cookies, noCookies, recordingVisual

int frame = 0;
int rippleCooldown = 0;

volatile bool recordingVisualShouldStop = false;

struct Ripple {
  float radius;
  float alpha;
};
std::vector<Ripple> ripples;

enum AppState {
  STANDBY,
  RECORDING,
  SENDING,
  COOKIE,
  NO_COOKIE
} currentState = STANDBY;

// turn motor - it doesn't matter to which side it rotates
// as long it rotates
void giveCandy () {
  digitalWrite(DISPENSER_PIN_2, HIGH);
}

// turn motor - it doesn't matter to which side it rotates
// as long as it rotates
void stopCandy () {
  digitalWrite(DISPENSER_PIN_2, LOW);
}

/**
Updates the current state (currentState) and activates the appropriate Task.
Uses a Semaphore (semState) for synchronization 
*/
void changeState(AppState newState) {
  currentState = newState;

  xSemaphoreGive(semState);
  switch (newState) {
    case STANDBY:    vTaskResume(taskHandles[0]); break;
    case RECORDING:
      vTaskResume(taskHandles[1]);
      vTaskResume(taskHandles[5]);
      break;
    case SENDING:    vTaskResume(taskHandles[2]); break;
    case COOKIE:     vTaskResume(taskHandles[3]); break;
    case NO_COOKIE:  vTaskResume(taskHandles[4]); break;
  }
}

/* connect to WiFi */
void connectToWiFi() {
  int myAttempts = 0;
  WiFi.mode(WIFI_STA);
  WiFi.disconnect(); //if connected before
  delay (100);
  Serial.print("Connecting to ");
  Serial.println(ssid);
  WiFi.useStaticBuffers(true);
  WiFi.begin(ssid, password);
  WiFi.setTxPower(WIFI_POWER_8_5dBm);
  
  while (WiFi.status() != WL_CONNECTED && myAttempts < 31) {
    Serial.print(".");
    delay(500);
    myAttempts++;
    if (myAttempts > 30) {
      Serial.println();
      Serial.print ("Not connected... Restarting.");
      ESP.restart();
    }
  }
  Serial.println();
  Serial.print("ESP32S3-Sense IP Address: ");
  Serial.println(WiFi.localIP());
}

/**
* Calculates a darker version of a color, for simulated transparency (TFT does not has a real alpha).
*/
uint16_t dimColor(uint16_t color, float factor) {
  uint8_t r = ((color >> 11) & 0x1F) * factor;
  uint8_t g = ((color >> 5) & 0x3F) * factor;
  uint8_t b = (color & 0x1F) * factor;
  return tft.color565(r << 3, g << 2, b << 3);
}

/**
* Shows a "breathing" animation, with a central pulsating circle.
* awaits a screen touch.
*/
void standbyTask(void* param) {
  uint16_t baseColor = tft.color565(0, 180, 255);
  int glowLayers = 15;
  sprite.fillSprite(TFT_BLACK);
  while (true) {
    if (currentState != STANDBY) vTaskSuspend(NULL);
    int radius = (int)(sin(frame * 0.1) * 10 + 30);
    for (int i = glowLayers; i > 0; i--) {
      float scale = 1.0 + i * 0.1;
      float alpha = 1.0 - (float)i / (glowLayers + 1);
      uint16_t glowColor = dimColor(baseColor, alpha);
      sprite.fillCircle(120, 120, radius * scale, glowColor);
    }
    sprite.fillCircle(120, 120, radius, baseColor);
    sprite.pushSprite(0, 0);
    frame++;
    vTaskDelay(pdMS_TO_TICKS(20));
  }
}

/**
* Shows a ripple effect during recording
* Uses std::vector<Ripple> to manage several growing waves with fade.
*/

void recordingVisualTask(void* param) {
  int radius = 20;
  uint16_t recordingColor = tft.color565(255, 0, 40);
  while (true) {
    if (currentState != RECORDING || recordingVisualShouldStop) {
      recordingVisualShouldStop = false;  // clears the flag
      vTaskSuspend(NULL);
    }
    sprite.fillSprite(TFT_BLACK);
    if (rippleCooldown <= 0) {
      ripples.push_back({(float)radius, 1.0f});
      rippleCooldown = 10;
    } else {
      rippleCooldown--;
    }
    for (int i = ripples.size() - 1; i >= 0; i--) {
      Ripple& r = ripples[i];
      r.alpha -= 0.02;
      r.radius += 2.0;
      if (r.alpha <= 0.0f) {
        ripples.erase(ripples.begin() + i);
        continue;
      }
      uint16_t rippleColor = dimColor(recordingColor, r.alpha);
      sprite.drawCircle(120, 120, (int)r.radius, rippleColor);
    }
    sprite.fillCircle(120, 120, radius, recordingColor);
    sprite.pushSprite(0, 0);
    frame++;
    vTaskDelay(pdMS_TO_TICKS(20));
  }
} 

/**
* Records 5 seconds of audio with I2S (PDM RX).
* keeps the recoring in a buffer 'wav_buffer', hence the PSRAM support
* sets the state to SENDING.
*/
void gravacaoTask(void* param) {
  while (true) {
    if (currentState != RECORDING) vTaskSuspend(NULL);
    I2SClass i2s;
    i2s.setPinsPdmRx(42, 41);
    i2s.begin(I2S_MODE_PDM_RX, 16000, I2S_DATA_BIT_WIDTH_16BIT, I2S_SLOT_MODE_MONO);
    uint8_t* buf = i2s.recordWAV(RECORD_TIME, &wav_size);
    memcpy(wav_buffer, buf, wav_size);
    free(buf);
    recordingVisualShouldStop = true;
    changeState(SENDING);
  }
}

/**
* Sends the audio for the local server via HTTP POST.
* Shows a "waiting" animation on the screen.
* Analyses the JSON response: if "positivo": true, sets state to COOKIE; else, NO_COOKIE.
*/
void sendTask(void* param) {
  while (true) {
    if (currentState != SENDING) vTaskSuspend(NULL);
    uint16_t baseColor = tft.color565(0, 150, 255);
    int numBars = 12;
    float angleStep = 360.0 / numBars;
    float radius = 50;
    int barLength = 12;
    int barWidth = 4;

    //sending the recording
    WiFiClient client;
    HTTPClient http;
    http.begin(client, apiUrl);
    http.addHeader("Content-Type", "audio/wav");
    int code = http.POST(wav_buffer, wav_size);

    // animation
    for (int f = 0; f < 150; f++) {
      sprite.fillSprite(TFT_BLACK);
      for (int i = 0; i < numBars; i++) {
        float angle = (frame * 4 + i * angleStep) * DEG_TO_RAD;
        float x = 120 + cos(angle) * radius;
        float y = 120 + sin(angle) * radius;
        float glowFactor = (sin((frame * 0.15) + i) + 1.0) / 2.0;
        float coreAlpha = 0.4 + 0.6 * glowFactor;
        float outerAlpha = 0.2 * glowFactor;
        uint16_t coreColor = dimColor(baseColor, coreAlpha);
        uint16_t glowColor = dimColor(baseColor, outerAlpha);
        sprite.fillRoundRect(x - barWidth / 2, y - barLength / 2, barWidth, barLength, 2, glowColor);
        sprite.fillRoundRect(x - barWidth / 2, y - barLength / 2, barWidth, barLength, 2, coreColor);
      }
      sprite.pushSprite(0, 0);
      frame++;
      vTaskDelay(pdMS_TO_TICKS(20));
    }

    if (code > 0) {
      String payload = http.getString();
      StaticJsonDocument<256> doc;
      if (!deserializeJson(doc, payload)) {
        bool positivo = doc["positivo"];
        changeState(positivo ? COOKIE : NO_COOKIE);
      } else changeState(NO_COOKIE);
    } else changeState(NO_COOKIE);

    http.end();
  }
}

int xpos = 0;
int ypos = 0;

/**
* Draw a cookie animation
*/

void drawCookie(PNGDRAW* pDraw) {
  uint16_t lineBuffer[MAX_IMAGE_WIDTH];
  uint8_t maskBuffer[1 + MAX_IMAGE_WIDTH / 8];
  png.getLineAsRGB565(pDraw, lineBuffer, PNG_RGB565_BIG_ENDIAN, 0xffffffff);
  if (png.getAlphaMask(pDraw, maskBuffer, 255)) {
    tft.pushMaskedImage(xpos, ypos + pDraw->y, pDraw->iWidth, 1, lineBuffer, maskBuffer);
  }
}

/**
* Shows a cookie image - PNG - at random positions
* Ativates the motor giveCandy() for 1 second
* After that, it calls stopCandy() and returns to standBy.
*/
void cookieTask(void* param) {
  while (true) {
    if (currentState != COOKIE) vTaskSuspend(NULL);
    tft.fillScreen(TFT_BLACK);
    unsigned long start = millis();
    const unsigned long duration = 1000; // how long the motor turns

    Serial.println ("Dispensing a candy...");
    // Turn the motor on for a candy
    giveCandy();

    while (millis() - start < duration) {
      xpos = random(0, tft.width() - 50);
      ypos = random(0, tft.height() - 50);

      int16_t rc = png.openFLASH((uint8_t *)cookie, sizeof(cookie), drawCookie);
      tft.startWrite();
      png.decode(NULL, 0);
      tft.endWrite();

      vTaskDelay(pdMS_TO_TICKS(200));
    }
    // Turn the motor off
    stopCandy();
    Serial.println ("Stoped dispensing a candy...");
    changeState(STANDBY);
  }
}

/**
* no_cookie drawing in the screen
*/
void drawNoCookie(PNGDRAW* pDraw) {
  uint16_t lineBuffer[MAX_IMAGE_WIDTH];
  png.getLineAsRGB565(pDraw, lineBuffer, PNG_RGB565_BIG_ENDIAN, 0xffffffff);
  tft.pushImage(0, pDraw->y, pDraw->iWidth, 1, lineBuffer);
}

/**
* Shows the no_cookie image for 5 seconds.
* returns to standBy.
*/
void noCookieTask(void* param) {
  while (true) {
    if (currentState != NO_COOKIE) vTaskSuspend(NULL);
    tft.fillScreen(TFT_BLACK);
    int16_t rc = png.openFLASH((uint8_t *)no_cookies, sizeof(no_cookies), [](PNGDRAW* pDraw) {
      uint16_t lineBuffer[MAX_IMAGE_WIDTH];
      png.getLineAsRGB565(pDraw, lineBuffer, PNG_RGB565_BIG_ENDIAN, 0xffffffff);
      tft.pushImage(0, pDraw->y, pDraw->iWidth, 1, lineBuffer);
    });
    png.decode(NULL, 0);
    delay(5000);
    changeState(STANDBY);
  }
}

/**
* Initialize the hardware: serie, screen, motor, Wi-Fi, touch, etc.
* Creates parallel tasks with xTaskCreatePinnedToCore for the several states: standby, gravação, envio, resposta.
*/
void setup() {
 
  Serial.begin(115200);

  delay (1000); //Waiting for it to settle

  currentState = STANDBY; //initial state

  pinMode(DISPENSER_PIN_2, OUTPUT);
  digitalWrite(DISPENSER_PIN_2, LOW);
  
  connectToWiFi();

  tft.init();
  tft.setRotation(0);
  sprite.setColorDepth(16);
  sprite.createSprite(240, 240);
  touch.begin();
  
  semState = xSemaphoreCreateBinary();
  xTaskCreatePinnedToCore(standbyTask, "standby", 4096, NULL, 1, &taskHandles[0], 0);
  xTaskCreatePinnedToCore(gravacaoTask, "gravacao", 4096, NULL, 1, &taskHandles[1], 0);
  xTaskCreatePinnedToCore(sendTask, "send", 4096, NULL, 1, &taskHandles[2], 0);
  xTaskCreatePinnedToCore(cookieTask, "cookie", 2048, NULL, 1, &taskHandles[3], 0);
  xTaskCreatePinnedToCore(noCookieTask, "nocookie", 2048, NULL, 1, &taskHandles[4], 0);
  xTaskCreatePinnedToCore(recordingVisualTask, "recordVis", 2048, NULL, 1, &taskHandles[5], 0);
}

/**
* main function
* Verifies if the screen has been touched while on standby.
* if yes, starts the recording task by switching the state
*/
void loop() {
  static bool touchedLastLoop = false;
  bool isTouched = touch.touched();
  if (isTouched && !touchedLastLoop && currentState == STANDBY) {
    Serial.println("Ecrã tocado. Iniciar gravação.");
    digitalWrite(DISPENSER_PIN_2, LOW);
    changeState(RECORDING);
  }
  touchedLastLoop = isTouched;
  vTaskDelay(pdMS_TO_TICKS(50));
}

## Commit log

2025-06-25 Added some new files
    [CandyDispenser_N20_Motor_Geared.stl, CandyDispenser_base.stl, CandyDispenser_cylinder.stl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]
2025-06-27 Added some images
    [CandyDispenser_jar.stl, CandyDispenser_jar_lid.stl]
2025-06-28 Arduino Client Readme
2025-06-28 Arduino files
2025-06-28 Schematics changed
2025-10-31 Added Nvidia Jetson Specific instructions
